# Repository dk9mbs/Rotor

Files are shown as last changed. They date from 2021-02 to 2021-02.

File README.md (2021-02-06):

https://forum.pycom.io/topic/4625/simple-http-server

micropython	
========================

```
cd /tmp/venv
python3.7 -m venv micropython
. /tmp/venv/micropython/bin/activate

pip install esptool
pip install adafruit-ampy

esptool.py --port /dev/ttyUSB0 erase_flash
esptool.py --port /dev/ttyUSB0 --baud 115200 write_flash --flash_size=detect 0 /tmp/esp8266-20200911-v1.13.bin

pip freeze
```

## Access to the python console

### Start picocom

```

ampy -p /dev/ttyUSB0 run --no-output rotor.py 
picocom --baud 115200 /dev/ttyUSB0

wget -O - --header "Rotor-Deg: 145" http://192.168.2.113/api/v1.0/rotor/0

```

### Exit picocom

```
ctrl-a ctrl-x
```

## Quellen

[1. Getting started with MicroPython on the ESP8266 — MicroPython 1.13 documentation](https://docs.micropython.org/en/latest/esp8266/tutorial/intro.html)

[Unable to exit serial tool · Issue #67 · amperka/ino · GitHub](https://github.com/amperka/ino/issues/67)

<https://www.digikey.com/en/maker/projects/micropython-basics-load-files-run-code/fb1fcedaf11e4547943abfdd8ad825ce>

https://github.com/micropython/micropython-lib/blob/master/traceback/traceback.py

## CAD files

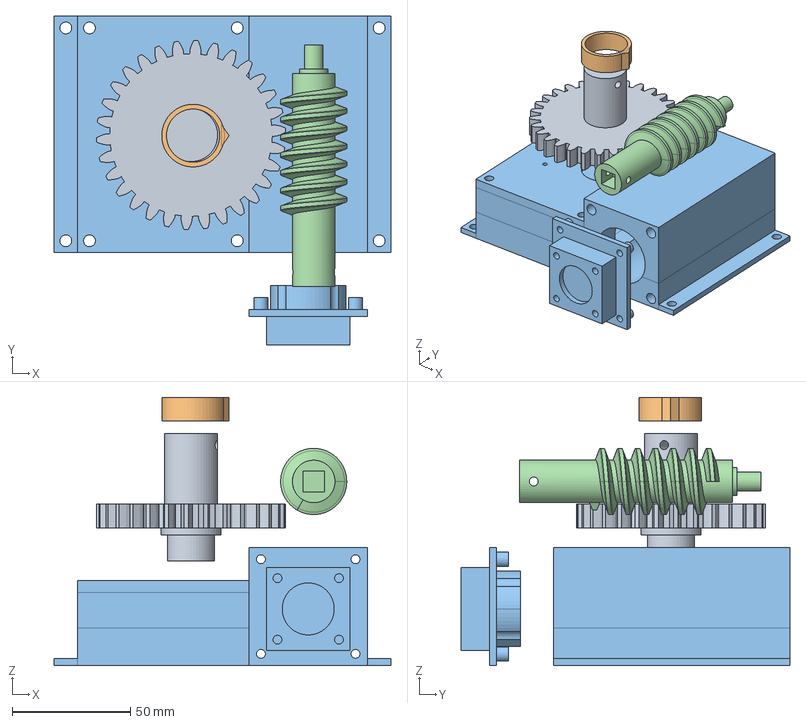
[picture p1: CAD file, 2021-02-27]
3D/assembly.FCStd
142.5 x 139.0 x 113.5 mm
Rotor_Antrieb_001
Rotor_Endabschalter_001
Rotor_Gehäuse_001
Rotor_Schnecke_001

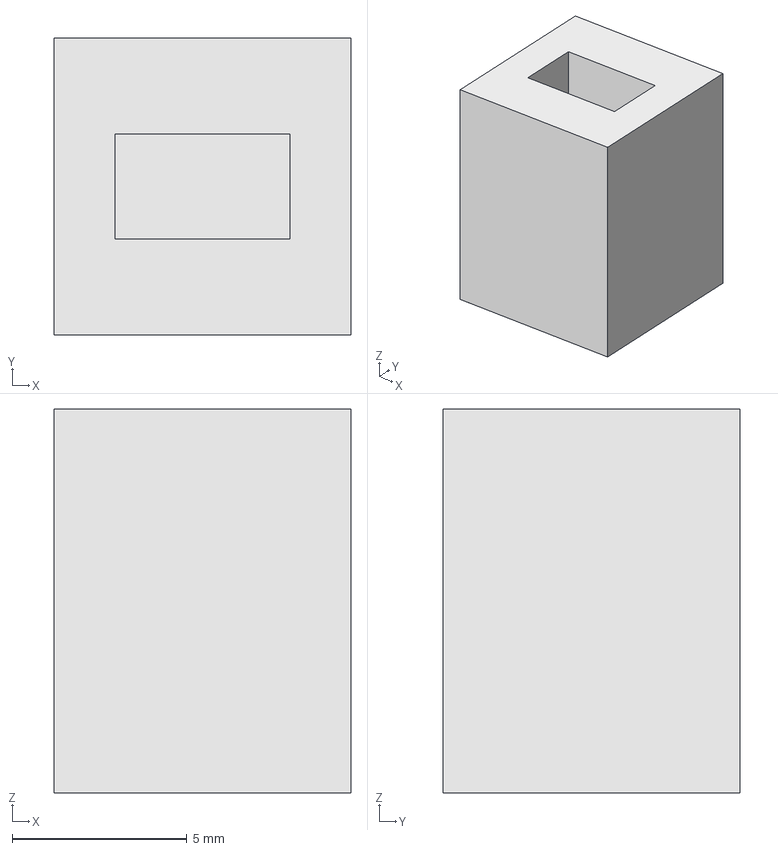
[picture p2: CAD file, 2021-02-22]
3D/Rotor_Schnecke_28BYJ-48_Adapter.FCStd
8.50 x 8.50 x 11.0 mm

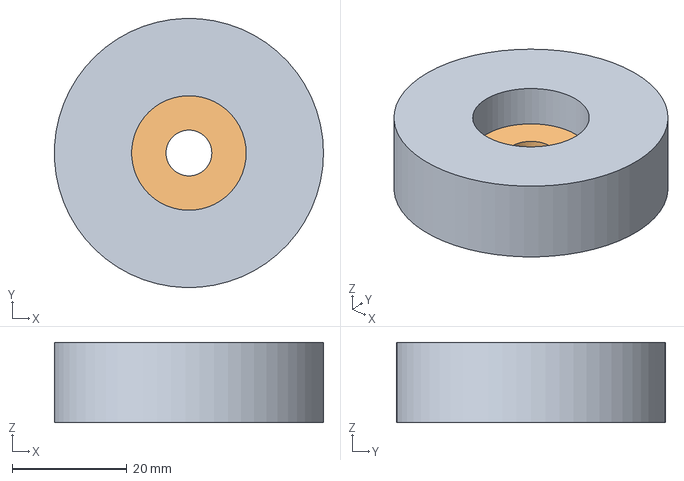
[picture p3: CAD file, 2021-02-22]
3D/Normteile.FCStd
47.0 x 47.0 x 14.0 mm
Kugellager 47mm Aussen 20mm Innen
Kugellager 22mm Aussen 8mm innen

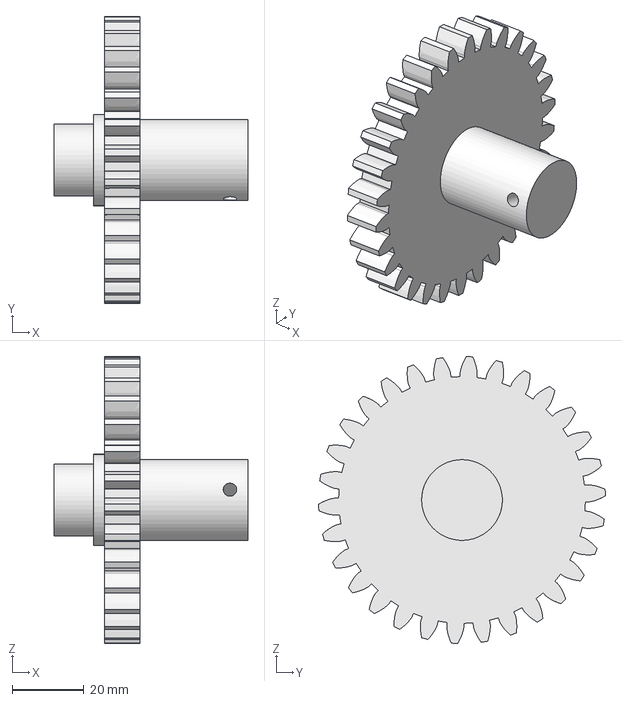
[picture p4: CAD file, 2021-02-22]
3D/Rotor_Antrieb.FCStd
54.0 x 80.0 x 80.0 mm

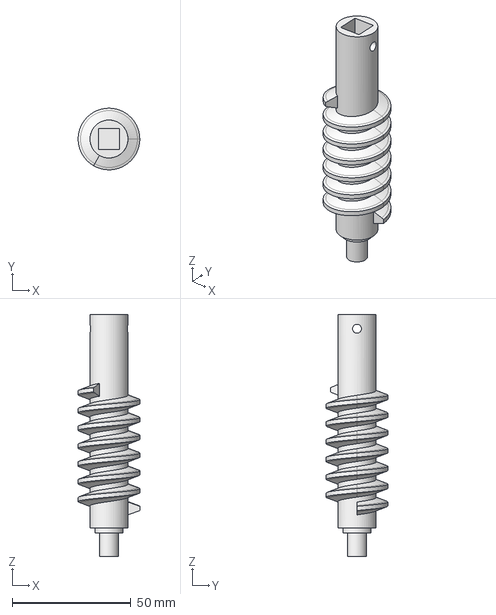
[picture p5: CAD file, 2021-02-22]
3D/Rotor_Schnecke.FCStd
26.0 x 26.0 x 102.0 mm

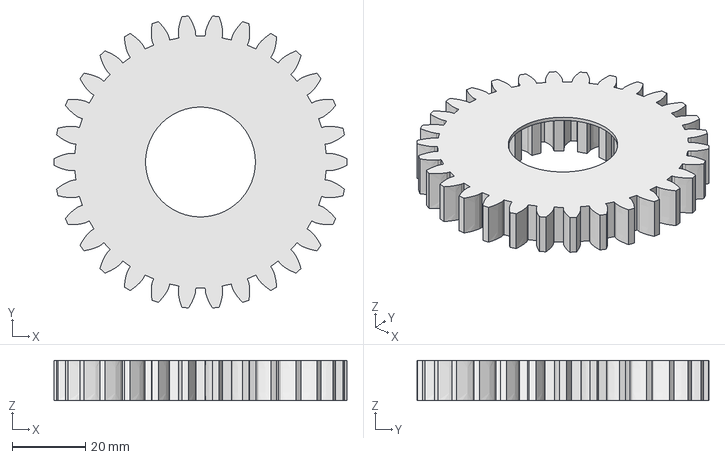
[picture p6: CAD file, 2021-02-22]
3D/Rotor_Adapter_Zahnrad.FCStd
80.0 x 79.7 x 11.0 mm

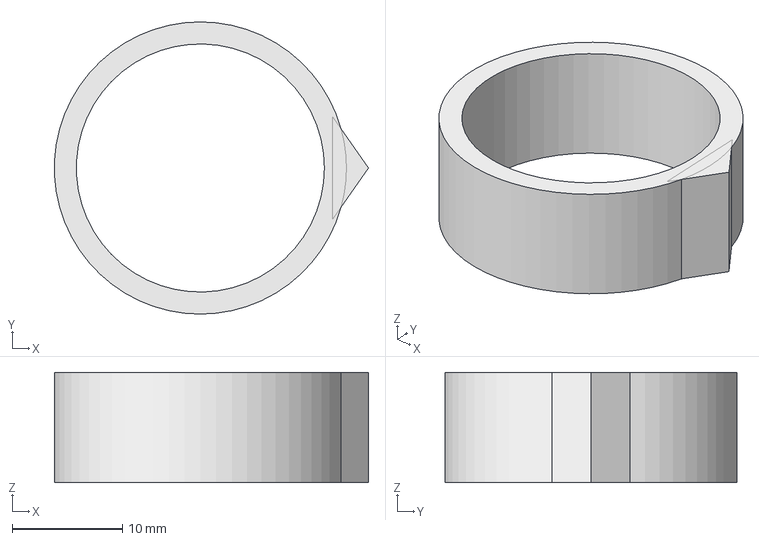
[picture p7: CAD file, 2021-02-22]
3D/Rotor_Endabschalter.FCStd
28.5 x 26.5 x 10.0 mm

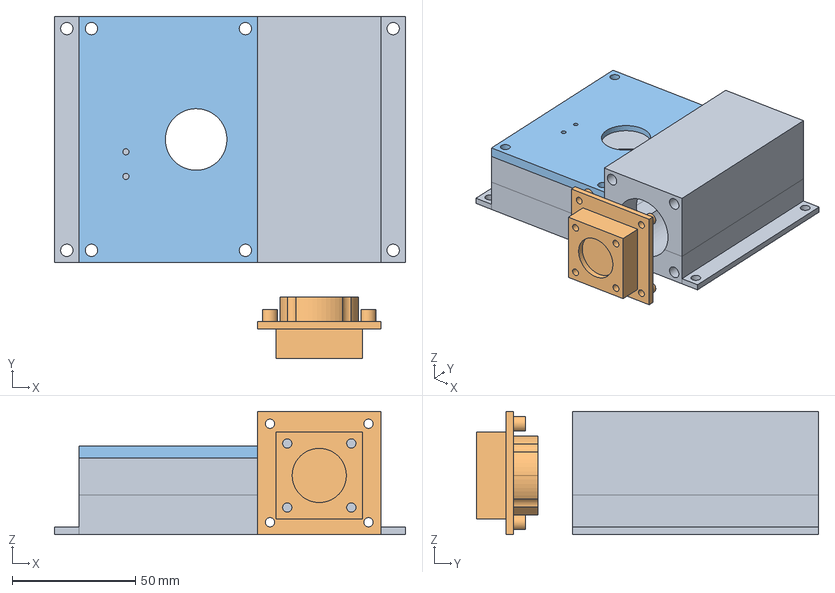
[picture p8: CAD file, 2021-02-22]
3D/Rotor_Gehäuse.FCStd
142.5 x 139.0 x 50.0 mm
Verschluss Tunnel Vorn
Deckel Stirnrad

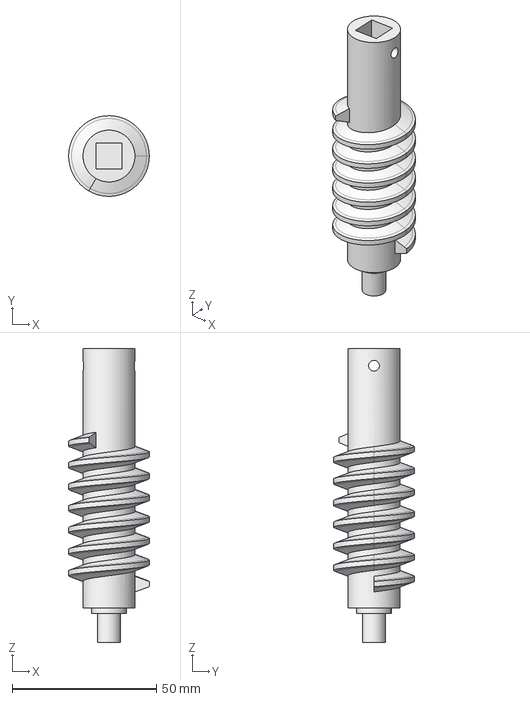
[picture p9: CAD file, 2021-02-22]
3D/Rotor_Schnecke_9mm.FCStd
28.0 x 28.0 x 102.0 mm

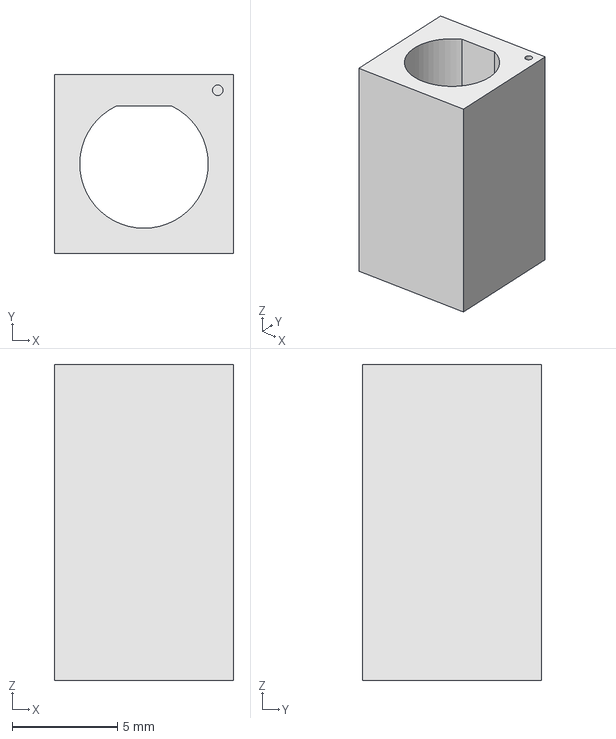
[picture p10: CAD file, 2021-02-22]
3D/Rotor_Schnecke_Nema14_Adapter.FCStd
8.50 x 8.50 x 15.0 mm

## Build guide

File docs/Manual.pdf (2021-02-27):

DK9MBS 3D Rotor V1.0

## Inhaltsverzeichnis

## Einrichtung

Die Setup Oberfläche der Rotors ist über einen beliebigen Webbrowser erreichbar. Bei gültiger WLAN Konfiguration meldet sich der Rotor automatisch am WLAN an und gibt die vom Router zugewiesene IP Adresse via Display und Serieller Schnittstelle aus (siehe dazu Kapitel Ausgabe). Beim ersten Start des Rotors oder bei ungültiger WLAN Konfiguration (WLAN am Standort nicht verfügbar, Passwort wurde geändert etc.) spannt der Rotor automatisch das WLAN „rotor.dk9mbs.de“ auf und zeigt das Passwort am LCD Display für ca. 2 Sekunden an. Im AP Modus ist der Rotor unter der IP Adresse 192.168.4.1 erreichbar.

## Setup

In der Setup Oberfläche können alle für den Betrieb des Rotors notwendigen Parameter hinterlegt.

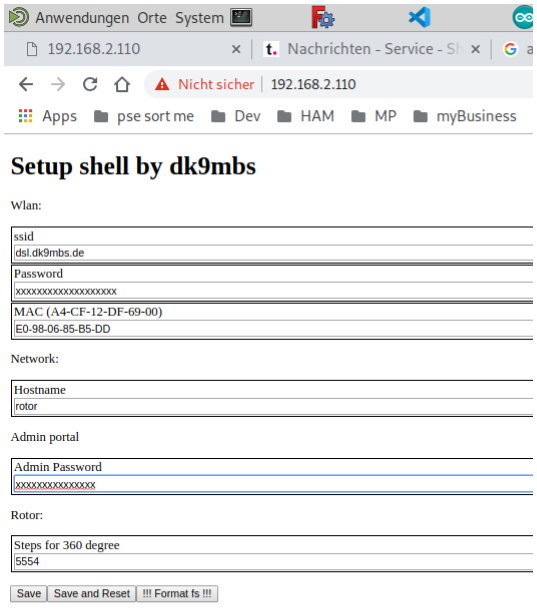
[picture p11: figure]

WLAN
ssid | Die WLAN ssid ID
Password | WLAN Passwort
MAC | Hier kann die MAC Adresse der ESP WLAN Netzwerkschnittstelle ändern.

Network
Hostname | Der Hostname unter dem sich der Rotor am DHCP Server registriert.

Admin Portal
Admin Password | Passwort für das Setup. Dieses Passwort wird auch für den AP Modus verwendet.

Rotor
Steps for 360 degree | Anzahl Schritte die der Motor für eine komplette Umdrehung benötigt (von Endschalter max. zu Endschalter min.). Durch löschen dieses Eintrags werden beim nächsten Neustart des Rotors dieSchritte automatisch neu ermittelt.

## Protokoll

Zur Rotor Steuerung mittels PC kommt ein generisches HTTP Protokoll zum Einsatz. Beispielsweise kann der Rotor mit „wget“ auf einfache Weise gesteuert werden:

wget -O – "http://[IP Adresse des Rotors]/api?command=[Kommando]&[Weitere Parameter]“

## Api

Neue Position setzen
Fährt den Rotor an eine neue Position. Als Argument „deg“ sind numerische Werte zwischen 0 und 360 (Grad) zulässig.

wget -O – "http://[IP Adresse des Rotors]/api?command=MOVE&deg=45“

Der HTTP Request arbeitet nicht blockierend – d.h. Nach Annahme des neuen Wertes liefert der Rotor sofort den HTTP Code 200 zurück. Erst danach startet der Motor. Eine Positionsänderung ist auch während laufenden Motor möglich.

Aktuelle Position abfragen
Liefert die aktuelle Position des Rotors.

wget -O – "http://[IP Adresse des Rotors]/api?command=GETCURRENTPOS“

Text auf dem Display ausgeben
Gibt einen Text auf dem Display in der obersten Zeile aus (max. 16 Zeichen).

wget -O – "http://[IP Adresse des Rotors]/api?command=SETDISPLAY&line0=Hallo“

In diesem Beispiel wird „Hallo“ in der ersten Zeile des LCD Displays angezeigt.

## Firmware (DK9MBS-Rotor-OS)

Die Architektur der Firmware basiert auf der „finate stamachine theory“. In dieser Theorie befindet sich die Firmware immer in einem definierten Zustand. Über Bedingungen kann ein Wechsel des Zustandes erzwungen werden.

Diagramm

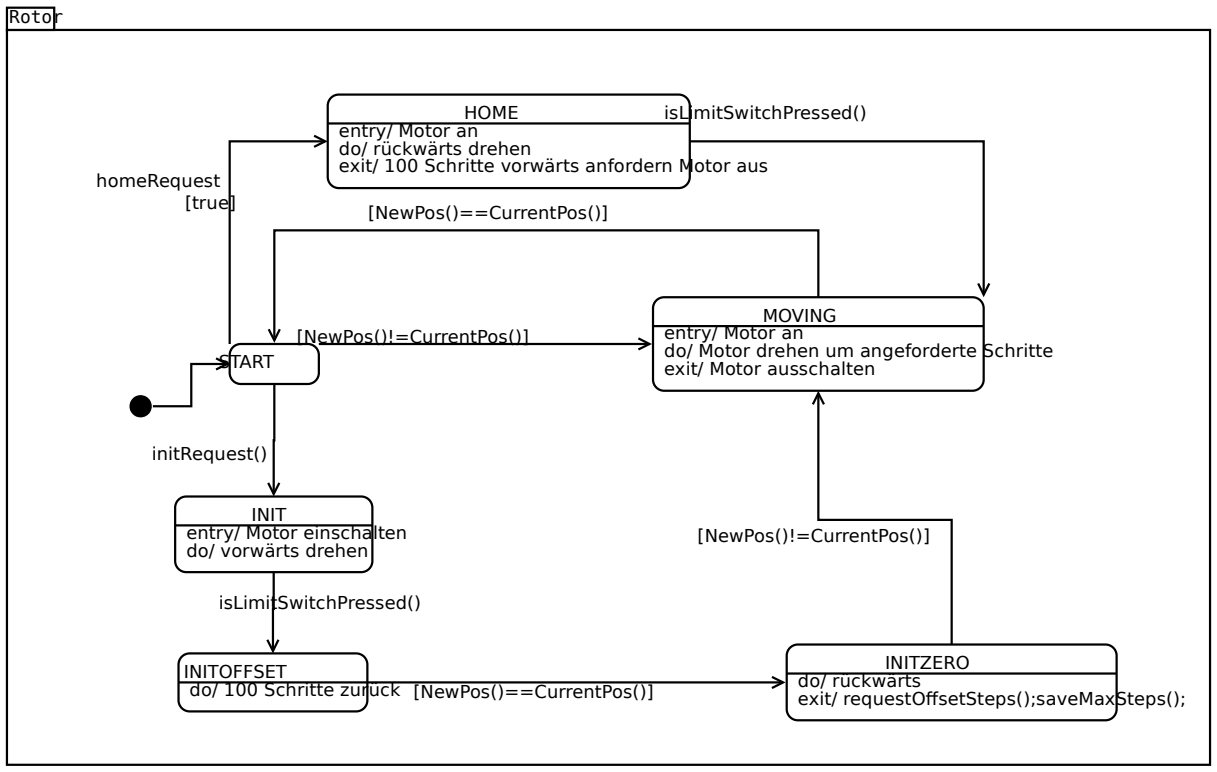
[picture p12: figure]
Rotor; START; [NewPos()!=CurrentPos()]; INIT entry/ Motor einschalten do/ vorwärts drehen; initRequest(); MOVING entry/ Motor an; exit/ Motor ausschalten; HOME entry/ Motor an do/ rückwärts drehen; INITOFFSET do/ 100 Schritte zurück; INITZERO do/ rückwärts exit/ requestOffsetSteps();saveMaxSteps();; [NewPos()==CurrentPos()]; isLimitSwitchPressed(); [true]; homeRequest

do/ Motor drehen um angeforderte Schritte exit/ 100 Schritte vorwärts anfordern Motor aus

Quellcode
Der Quellcode kann unter Github öffentlich eingesehen werden. Die Adresse lautet:

https://github.com/dk9mbs/Rotor/blob/dev/fw-8266-arduino/fw-8266-arduino.ino

Bibliotheken

LiquidCrystal_I2C https://github.com/lucasmaziero/ LiquidCrystal_I2C

Manuell installieren

Einstellungen Arduino IDE
Zunächst muss das ESP Board der Arduino IDE bekanntgemacht werden. Dazu muss die URL der Board Definition unter Datei → Voreinstellungen als Zusätzliche Boardverwalter-URL hinterlegt werden [4].

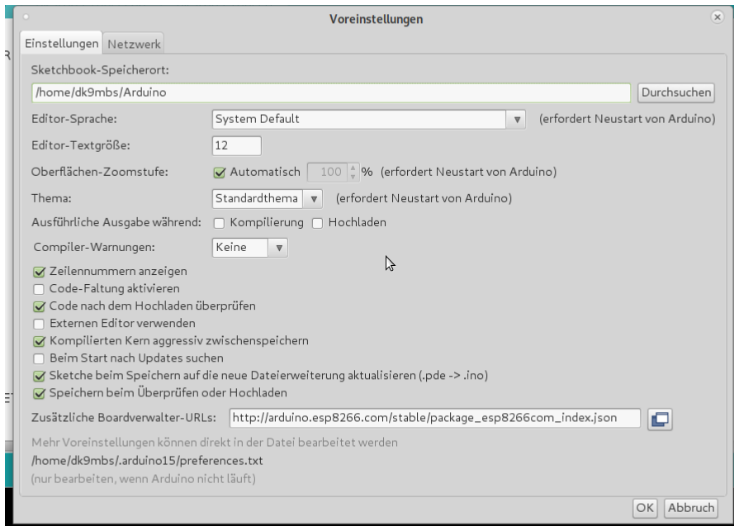
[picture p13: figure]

Die zu hinterlegende URL lautet: http://arduino.esp8266.com/stable/package_esp8266com_index.json

Jetzt kann unter Werkzeuge das richtige Board ausgewählt werden: NodeMCU 0.9 (ESP-12 Module).

## Mainboard

Auf dem Rotor Mainboard befinden sich sowohl NodeMCU mit ESP8266, DRV8825 als auch sämtliche Anschlüsse und die Stromversorgung (12V und 5V).

## Anschlüsse

Die Anschlüsse sind mit C1 – C5 gekennzeichnet.

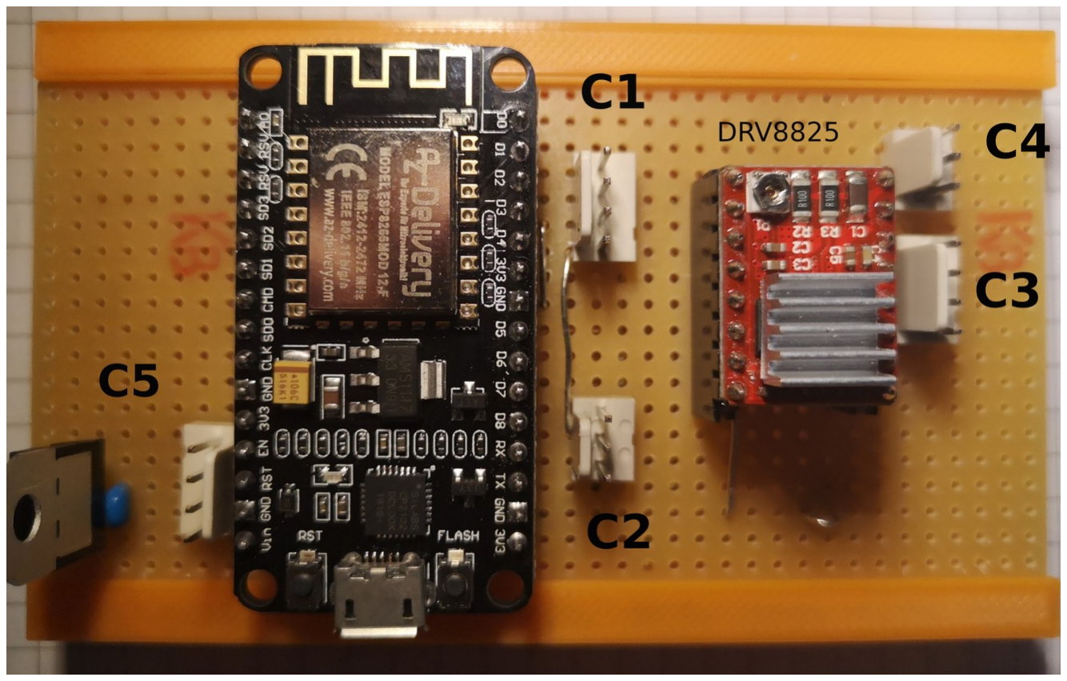
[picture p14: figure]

Connector | Pin (von oben nach unten) | Beschreibung
C1 | | I2C Bus
| 1 | SCL
| 2 | SDA
| 3 | GND
| 4 | +5V (Vin)
C2 | | Endschalter
| 1 | nc
| 2 | Taster
| 3 | GND
C3 | | Stepper
| 1 | B2
| 2 | B1
| 3 | A1
| 4 | A2
C4 | | Power (12V)

| 1 | nc
| 2 | +12V in
| 3 | GND
C5 | | Nicht benutzt
| 1
| 2
| 3
| 4 | + 5V (Vin)

## Elektronische Komponenten

## NodeMCU mit ESP8266

Verfügbare GPIO Pin‘s
Nicht alle Pins können frei verwendet werden. Beispielsweise darf Pin 2 beim Booten nicht auf Masse gezogen sein.
GPIO | Function | State | Einschränkungen
0 | Boot mode select | 3.3V | No Hi-Z
1 | TX0 | - | Not usable during Serial transmission
2 | Boot mode select TX1 | 3.3V (boot only) | Don’t connect to ground at boot time Sends debug data at boot time
3 | RX0 | - | Not usable during Serial transmission
4 | SDA (I²C) | - | -
5 | SCL (I²C) | - | -
6-11 | Flash connection | x | Not usable, and not broken out
12 | MISO (SPI) | - | -
13 | MOSI (SPI) | - | -
14 | SCK (SPI) | - | -
15 | SS (SPI) | 0V | Pull-up resistor not usable
16 | Wake up from sleep | - | No pull-up resistor, but pull-down instead Should be connected to RST to wake up

Quelle: [1]

Verwendung der GPIO Pins

Pin | Verwendung | Bemerkung
12 | 8825 - Step
13 | 8825 - Direction
14 | 8825 - Enable
4 | LCD (SDA) | 10K Pulldown
5 | LCD (SCL)
2 | Endschalter | 4,7K Pullup Schließer

Pinbelegung
In diesem Manual wird immer von den GPIO Bezeichnungen gesprochen; nicht von den auf dem Board aufgedruckten Aliassen.

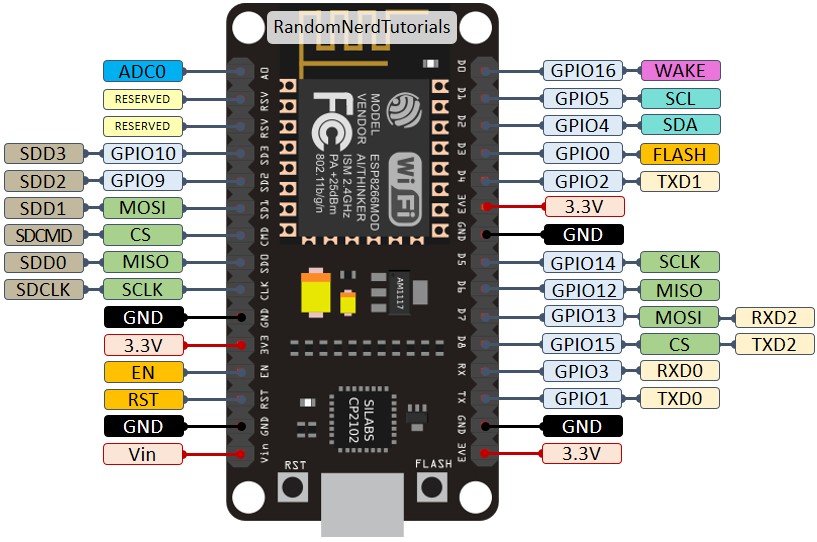
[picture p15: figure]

## Motortreiber DRV8825

Bei dem DRV8825 handelt es sich um einen intelligenten Schrittmotortreiber. Dieser Treiber benötigt vom Mikrocontroller lediglich Schritt Impulse. Die eigentliche Ansteuerung des Schrittmotors übernimmt der Treiber selbst.

Pinbelegung
Vor dem Betrieb mit einem neuen Motor muss der maximale Strom mit dem Potentiometer laut Herstellerangabe eingestellt werden.

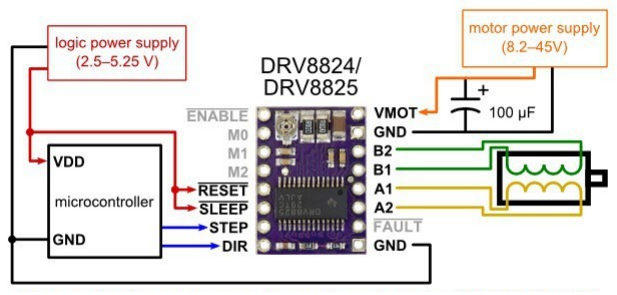
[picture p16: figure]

Konfiguration der Schrittgröße
Über die Anschlüsse „M0“ bis „M2“ kann die Schrittgröße konfiguriert werden. Nach Änderung der Schrittgröße muss im Setup Modus des Rotors diese auf 0 gesetzt werden. Nach dem nächsten Neustart ermittelt der Rotor dann selbstständig die Anzahl der Schritte die für eine 360 Grad Drehung benötigt werden und speichert diese dauerhaft.
M0 | M1 | M2 | Schritt Auflösung | Anzahl Schritte für eine Umdrehung
0 | 0 | 0 | 1 | 200
1 | 0 | 0 | 1/2 | 400
0 | 1 | 0 | 1/4 | 800
1 | 1 | 0 | 1/8 | 1600
0 | 0 | 1 | 1/16 | 3200
1 | 0 | 1 | 1/32 | 6400

Signal am Step Eingang
Am Step Eingang des DRV8825 ist beim Bewegen des Rotors ein 50Hz (20ms Periodendauer) Signal zu erkennen.

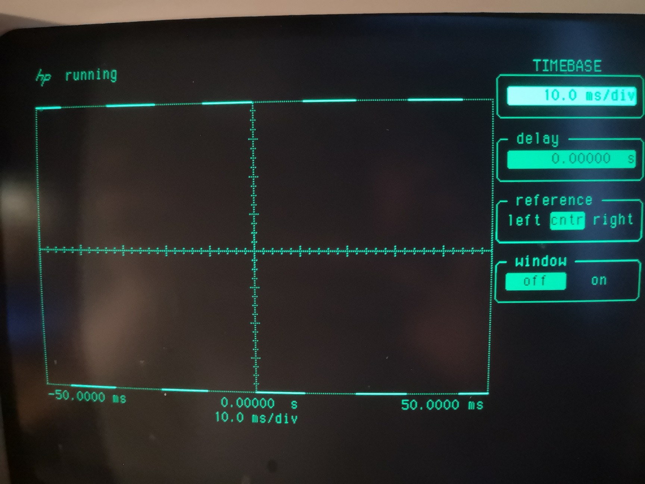
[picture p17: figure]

## Ausgabe

Die Ausgabe von Meldungen erfolgt bei dem Rotor auf 2 Wegen:
- Über den Seriellen Port mit 115200 Baud
- Über ein am I2C Bus angeschlossenes LCD Display
Das LCD Display zeigt im Betrieb die IP Adresse des Rotors im Netzwerk und die aktuelle Position in (Alt) Grad an.

LCD Display mit I2C Adapter

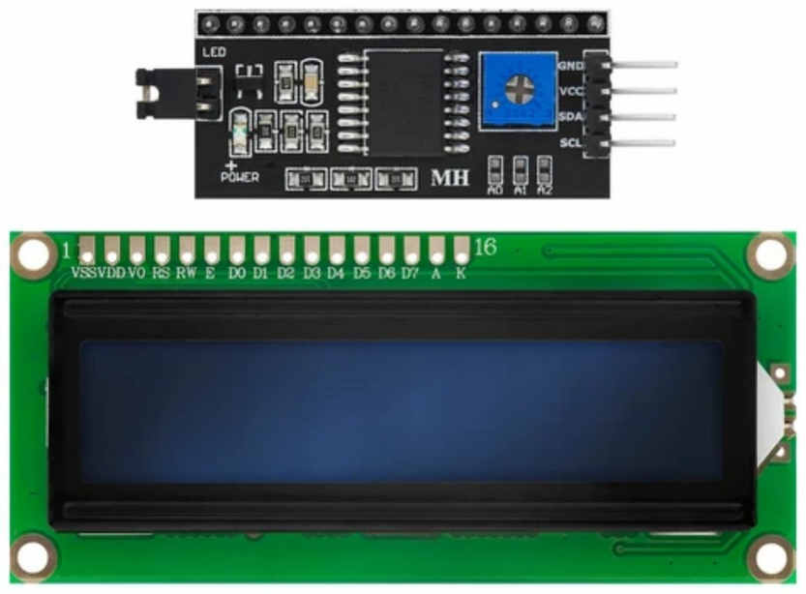
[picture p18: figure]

## 3D Druck

Die Mechanik des Rotors besteht lediglich aus 3D druckbaren Komponenten und einigen wenigen Standardbauteilen die in jedem Baumarkt verfügbar sind.

## Explosionszeichnung

Der Rotor besteht aus einzelnen Bauteilen. Als Druckmaterial wird PLA empfohlen.

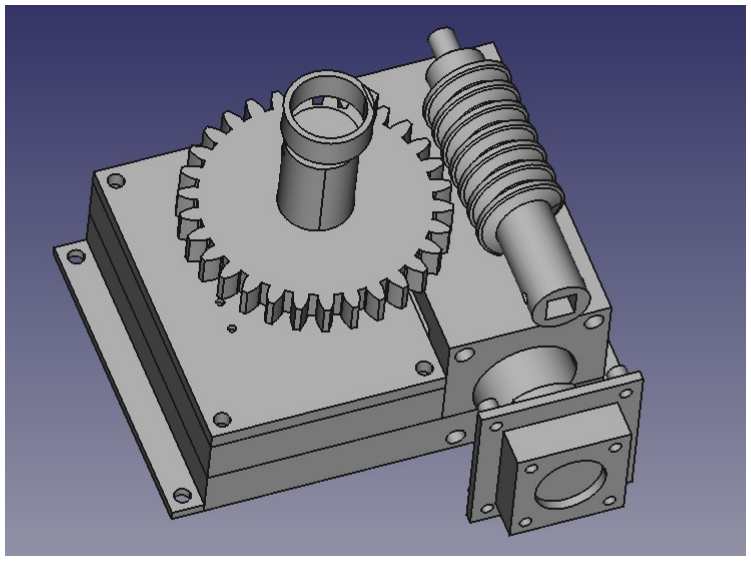
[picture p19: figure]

## Dateien

Die Dateien stehen im Freecad Format zur Verfügung. Die Druckdauer beträgt je nach Einstellung und Geschwindigkeit des Druckers ca. 60 Stunden. Die Freecad Dateien können hier runter geladen werden:
https://github.com/dk9mbs/Rotor/tree/master/3D
Eine kurze Beschreibung der einzelnen Teile befindet sich in diesem Handbuch im Kapitel „Stückliste“

## Stückliste

## Elektronik / Mechanik

Menge | Teil
1 | DRV8825
1 | NodeMCU mit 8266
1 | LCD Display 16X2 Zeichen
1 | LCD I2C Adapter
1 | Kugellager 47mm Außendurchmesser
1 | Kugellager 22mm Außendurchmesser
1 | Endschalter (Taster Schließer)
1 | M3 Gewindestange
4 | M4 Schrauben
4 | M4 Muttern
8 | M3 Muttern
8 | M3 Unterlegscheiben

## 3D Teile

Dateiname | Baugruppe
Rotor_Antrieb.FCStd | Zahnrad mit Antriebsachse
Rotor_Endabschalter.FCStd | Endschalter Ring
Rotor_Gehäuse.FCStd | Gehäuse mit Deckel und Nema Befestigung
Rotor_Schnecke_9mm.FCStd | Antriebsschnecke
Rotor_Schnecke_Nema14_Adapter.FCStd | Adapter Motor - Schnecke

## Verbesserungen in den nächsten Versionen

In einer nächsten Versionen sind Verbesserungen sowohl an der Firmware, der Elektronik und der Mechanik geplant.

## Verbesserungen

Problem | Lösung | Prio (1-9)
Update | Over the Air Updates | 9
Fehlende manuelle Bedienung (keine freien GPIO Pin‘s) | Anschluss I2C Port Expander | 1
Laute Motorgeräusche | Dämpfung zwischen Motor und Gehäuse | 2
Drehmoment nicht bekannt | Messen mit Kofferwaage | 1
2. Rotor

## Quellen

[1] https://lastminuteengineers.com/drv8825-stepper-motor-driver-arduino-tutorial/
[2] https://tttapa.github.io/ESP8266/Chap04%20-%20Microcontroller.html
[3] https://de.wikipedia.org/wiki/Endlicher_Automat
[4] https://m.heise.de/make/artikel/ESP-Boards-mit-der-Arduino-IDE-programmieren-4130861.html?seite=all (https://m.heise.de/make/artikel/ESP-Boards-mit-der-Arduino-IDE-programmieren-4130861.html?seite=all)
[5] https://github.com/dk9mbs/Rotor/tree/master/3D

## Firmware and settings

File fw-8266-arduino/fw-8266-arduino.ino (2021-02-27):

#ifdef ESP32
#pragma message(THIS EXAMPLE IS FOR ESP8266 ONLY!)
#error Select ESP8266 board.
#endif

#include "dk9mbs_tools.h"
#include <ESP8266WiFi.h>
#include <FS.h>
#include <ESP8266WebServer.h>
#include <ESP8266HTTPClient.h>
#include <LiquidCrystal_I2C.h>
#include "config.h"

#define ROT_AZI_STEP 12
#define ROT_AZI_DIR 13
#define ROT_AZI_ENABLED 14
#define ROT_AZI_LIMIT_SWITCH 2
#define SW1PIN 4
#define SW2PIN 5
#define LIMIT_SWITCH_OFFSET 100

enum {START, MOVING, INIT,INITOFFSET,INITZERO, HOME,HOMEOFFSET};
enum {FORWARD, BACKWARD, STOPPED};

class Rotor {
  private:
    int _state;
    int _newPos;
    int _currentPos;
    int _maxSteps;
    boolean _initRequest;
    boolean _homeRequest;
       
  public:
    Rotor();

    boolean getInitRequest();
    void setInitRequest(boolean value);
    boolean getHomeRequest();
    void setHomeRequest(boolean value);
    
    int getState();
    void setState(int value);
  
    int getNewPos();
    void setNewPos(int value);

    int getCurrentPos();
    void setCurrentPos(int value);
    void incrementCurrentPos();
    void decrementCurrentPos();

    void incrementMaxSteps();
    int getMaxSteps();
    void setMaxSteps(int value);

    int getCurrentPosDeg();
    void setNewPosDeg(int deg);

};
Rotor::Rotor() {
  Rotor::_state=START;
  Rotor::_newPos=0;
  Rotor::_currentPos=0;
  Rotor::_maxSteps=0;
  Rotor::_initRequest=false;
}
int Rotor::getNewPos() {
  return Rotor::_newPos;
}
void Rotor::setNewPos(int value) {
  Rotor::_newPos=value;
}
int Rotor::getCurrentPos(){
  return Rotor::_currentPos;
}
void Rotor::setCurrentPos(int value){
  Rotor::_currentPos=value;
}
void Rotor::incrementCurrentPos(){
  Rotor::_currentPos++;
}
void Rotor::decrementCurrentPos(){
  Rotor::_currentPos--;
}
void Rotor::incrementMaxSteps(){
  Rotor::_maxSteps++;
}
int Rotor::getMaxSteps() {
  return Rotor::_maxSteps;
}
void Rotor::setMaxSteps(int value){
  Rotor::_maxSteps=value;
}
void Rotor::setInitRequest(boolean init) {
  Rotor::_initRequest=init;
}
boolean Rotor::getInitRequest() {
  return Rotor::_initRequest;
}

void Rotor::setHomeRequest(boolean init) {
  Rotor::_homeRequest=init;
}
boolean Rotor::getHomeRequest() {
  return Rotor::_homeRequest;
}


int Rotor::getState() {
  return Rotor::_state;
}
void Rotor::setState(int value){
  Rotor::_state=value;
}

int Rotor::getCurrentPosDeg() {
  float deg;
  deg=((float)360/(float)Rotor::_maxSteps)*(float)Rotor::_currentPos;
  return (int)deg;
}

void Rotor::setNewPosDeg(int deg) {
  int steps;
  steps=((float)Rotor::_maxSteps/(float)360)*(float)deg;
  Rotor::_newPos=(int)steps;
}

WiFiClient espClient;
ESP8266WebServer httpServer(80);
HTTPClient http;
LiquidCrystal_I2C lcd(0x27, 16, 2);
Rotor rotor;
boolean runSetup=false;


void setup()
{
  Serial.begin(115200);
  lcd.begin();

  disableStepper(rotor);
  printLcd(lcd, 0,1, "init",1);
  
  setupIo();
  printLcd(lcd, 5,1, ".",0);
  setupFileSystem();
  printLcd(lcd, 6,1, ".",0);

  Serial.print("Setup:");
  Serial.println(digitalRead(SW1PIN));
  Serial.print("adminpwd: ");
  Serial.println(readConfigValue("adminpwd"));
  Serial.print("Steps for 360 degree: ");
  Serial.println(readConfigValue("rotorsteps"));
  printLcd(lcd, 7,1, ".",0);
  delay (1000);  

  if(runSetup) {
    setupWifiAP();
    setupHttpAdmin();
  } else {
    setupHttpAdmin();
    if (!setupWifiSTA(readConfigValue("ssid").c_str(), readConfigValue("password").c_str(), readConfigValue("mac").c_str())) {
      // Fallback start the AP mode!
      printLcd(lcd, 0,0, "No WLAN! AP mode",0);
      setupWifiAP();
      delay(2500);
    }

    Serial.println("Waiting for commands over http...");
    delay(1000);

    rotor.setMaxSteps(readMaxStepsFromSetup());
    if(rotor.getMaxSteps()==0){
      Serial.println("No data for stepper found!");
      rotor.setInitRequest(true);
    } else {
      Serial.println("Move stepper to home position");
      rotor.setHomeRequest(true);
    }
  } 
}

void loop()
{
  static unsigned long lastSw1=0;
  static unsigned long lastSw2=0;

  httpServer.handleClient(); 
  rotorStepperStateMaschine(rotor);

  if(digitalRead(SW1PIN)==HIGH && millis() > lastSw1+500) {
    //Serial.println("SW1");
    lastSw1=millis();
  }

  if(digitalRead(SW2PIN)==HIGH && millis() > lastSw2+500) {
    //Serial.println("SW2");
    lastSw2=millis();
  }

}

void rotorStepperStateMaschine(Rotor &rotor) {
  int state;
  static int lastEntryState=-1;
  static unsigned long lastLoop=0;
  static unsigned long lastLcd=0;
  
  state=rotor.getState();
  
  int newPos=rotor.getNewPos();
  int currentPos=rotor.getCurrentPos();
  int rotorDir;

  rotorDir=calculaterotorDirection(rotor);

  switch (state) {
    case HOME:
      if (state!=lastEntryState){
        rotor.setHomeRequest(false);
        enableStepper(rotor);
        lastEntryState=state;
        Serial.println("Entry point HOME");
        clearLcdLine(lcd,1);
        printLcd(lcd, 0,1, "go home",0);
      }else if(isLimitSwitchPressed(rotor)==true) {
        rotor.setCurrentPos(-LIMIT_SWITCH_OFFSET);
        rotor.setNewPos(0);
        disableStepper(rotor);
        state=MOVING;
      } else {
        if (millis() > lastLoop + 1) {
          doStep(BACKWARD, rotor);
          lastLoop=millis();    
        }
      }      
      break;
    case START:
      if (state!=lastEntryState){
          lastEntryState=state;

          if(rotor.getHomeRequest()) state=HOME;
          if(rotor.getInitRequest()) state=INIT;
          Serial.println("Entry point START");
          clearLcdLine(lcd,1);
          printLcd(lcd, 0,1, "Pos:"+String(rotor.getCurrentPosDeg())+"\337",0); //col, row

      } else if(newPos!=currentPos){
          Serial.println(newPos);
          Serial.println("Statemaschine is starting...");
          enableStepper(rotor);
          state=MOVING;
      } else {
        // no do actions in this state!!!
      }
      break;
    case INIT:
      if (state!=lastEntryState){
        rotor.setInitRequest(false);
        enableStepper(rotor);
        lastEntryState=state;
        Serial.println("Entry point INIT");
        clearLcdLine(lcd,1);
        printLcd(lcd, 0,1, "move to max",0);
      }

      if(isLimitSwitchPressed(rotor)==true) {
        rotor.setNewPos(rotor.getCurrentPos()-LIMIT_SWITCH_OFFSET);
        state=INITOFFSET;
      } else {
        if (millis() > lastLoop + 1) {
          doStep(FORWARD, rotor);
          lastLoop=millis();    
        }
      }
      break;

    case INITOFFSET:
      if (state!=lastEntryState){
          lastEntryState=state;
          Serial.println("Entry point INITOFFSET");
          clearLcdLine(lcd,1);
          printLcd(lcd, 0,1, "move to offset",0);
      }

      if(newPos==currentPos){
        disableStepper(rotor);
        state=INITZERO;
      } else {
        if (millis() > lastLoop + 1) {
          doStep(BACKWARD, rotor);
          lastLoop=millis();
        }
      }
      break;    
    case INITZERO:
      if (state!=lastEntryState){
          enableStepper(rotor);
          rotor.setMaxSteps(0);
          lastEntryState=state;
          Serial.println("Entry point INITZERO");
          clearLcdLine(lcd,1);
          printLcd(lcd, 0,1, "move home",0);
      }
      
      if(isLimitSwitchPressed(rotor)==true) {
        rotor.setCurrentPos(LIMIT_SWITCH_OFFSET*-1);
        rotor.setNewPos(0);
        Serial.println("Steps required for 360 degree:"+(String)rotor.getMaxSteps());
        saveConfigValue("rotorsteps", (String)(rotor.getMaxSteps()-LIMIT_SWITCH_OFFSET));
        state=MOVING;
      } else {
        if (millis() > lastLoop + 1) {
          if(doStep(BACKWARD, rotor)==true){
            rotor.incrementMaxSteps();
          }
          lastLoop=millis();    
        }
      }
      break;

    case MOVING:
      if (state!=lastEntryState){
        enableStepper(rotor);          
        lastEntryState=state;
        Serial.println("Entry point MOVING");
        clearLcdLine(lcd,1);
        printLcd(lcd, 0,1, "moving...",0); 
      }
    
      if(newPos==currentPos){
        disableStepper(rotor);
        state=START;
      } else {
        if (millis() > lastLoop + 10) {
          doStep(rotorDir, rotor);
          lastLoop=millis();
        }

      }
      
      break;
  }

  rotor.setState(state);
}

/*
 * 
 * Helper functions
 * 
 */

void enableStepper(Rotor &rotor) {
  digitalWrite(ROT_AZI_ENABLED, LOW);
}

void disableStepper(Rotor &rotor) {
  digitalWrite(ROT_AZI_ENABLED, HIGH);
}

boolean isLimitSwitchPressed(Rotor &rotor) {
  if(digitalRead(ROT_AZI_LIMIT_SWITCH)==LOW) {
    return true;
  } else {
    return false;
  }
}

boolean doStep(int rotorDir, Rotor &rotor) {
  boolean dirPin=LOW;
  boolean result=false;
  
  if (rotorDir==BACKWARD) {
    dirPin=HIGH;
    //dirPin=LOW;
  }
  
  digitalWrite(ROT_AZI_DIR, dirPin);

  if (digitalRead(ROT_AZI_STEP)){
      digitalWrite(ROT_AZI_STEP,LOW);
      //increment or decrement the current pos only at every low high pass
      result=true;
      if (rotorDir==BACKWARD) {
        rotor.decrementCurrentPos();
      } else {
        rotor.incrementCurrentPos();
      }
    } else {
    digitalWrite(ROT_AZI_STEP, HIGH);
  }

  return result;
}

int calculaterotorDirection(Rotor &rotor) {
  int rotorDir;
  rotorDir=STOPPED;
  
  if (rotor.getNewPos()<rotor.getCurrentPos()) {
    rotorDir=BACKWARD;
  } else {
    rotorDir=FORWARD;
  }

  return rotorDir;
}

int readMaxStepsFromSetup(){
  String tmp;
  tmp=readConfigValue("rotorsteps");
  if(tmp=="" || tmp=="0"){
    return 0;
  }

  return tmp.toInt();
}

/*
   getCommandValue
   Return a part of a complete Stepper command.
   Example:
   getCommandValue("MF 100", ' ',2)
   Return 100
*/
String getCommandValue(String data, char separator, int index)
{
  int found = 0;
  int strIndex[] = {0, -1};
  int maxIndex = data.length() - 1;

  for (int i = 0; i <= maxIndex && found <= index; i++) {
    if (data.charAt(i) == separator || i == maxIndex) {
      found++;
      strIndex[0] = strIndex[1] + 1;
      strIndex[1] = (i == maxIndex) ? i + 1 : i;
    }
  }

  return found > index ? data.substring(strIndex[0], strIndex[1]) : "";
}


String createIoTDeviceAddress(String postfix) {
  String address=String(readConfigValue("mac")+"."+postfix);
  address.replace("-","");
  return address;  
}

void setupHttpAdmin() {
  httpServer.on("/",handleHttpSetup);
  httpServer.on("/api",handleHttpApi);
  httpServer.onNotFound(handleHttp404);
  httpServer.begin();
}

void handleHttpApi() {
  String cmd=httpServer.arg("command");
  String steps=httpServer.arg("steps");
  String deg=httpServer.arg("deg");
  String line0=httpServer.arg("line0");
  String responseBody="api";
  
  if(cmd=="ping") {
    responseBody="pong";
  } else if(cmd=="MOVE") {

    if(rotor.getState()==INIT || rotor.getState()==INITOFFSET || rotor.getState()==INITZERO){
      httpServer.send(500, "text/html", "Rotor zeroinit in progress!"); 
      return;
      
    }
    //rotor.setNewPos(steps.toInt());
    rotor.setNewPosDeg(deg.toInt());
    Serial.println("New pos:"+((String)rotor.getNewPos()));
    Serial.println("Current pos:"+((String)rotor.getCurrentPos()));
  } else if (cmd=="GETCURRENTPOS") {
    responseBody=(String)rotor.getCurrentPos();
  } else if (cmd =="SETDISPLAY"){
    clearLcdLine(lcd,0);
    printLcd(lcd, 0,0, line0,0); //col, row
    responseBody=String(line0);
  }

  httpServer.send(200, "text/html", responseBody); 
}

void handleHttpSetup() {
    String pwd = readConfigValue("adminpwd");
    if (!httpServer.authenticate("admin", pwd.c_str())) {
      return httpServer.requestAuthentication();
    }
      
    if(httpServer.hasArg("CMD")) {
      Serial.println(httpServer.arg("CMD"));
      handleSubmit();
    }

    if(httpServer.hasArg("FORMATFS")) {
      Serial.println("Format FS");
      handleFormat();
    }
    if(httpServer.hasArg("RESET")) {
      Serial.println("Reset ...");
      handleReset();
    }

    String html =
    "<!DOCTYPE HTML>"
    "<html>"
    "<head>"
    "<meta name = \"viewport\" content = \"width = device-width, initial-scale = 1.0, maximum-scale = 1.0, user-scalable=0\">"
    "<title>DK9MBS-ROTOR-OS</title>"
    "<style>"
    "\"body { background-color: #808080; font-family: Arial, Helvetica, Sans-Serif; Color: #000000; }\""
    "</style>"
    "</head>"
    "<body>"
    "<h1>DK9MBS-Rotor-OS Setup</h1>"
    "<FORM action=\"/\" method=\"post\">"
    "<P>Wlan:"
    "<INPUT type=\"hidden\" name=\"CMD\" value=\"SAVE\"><BR>"
    "<div style=\"border-style: solid; border-width:thin; border-color: #000000;padding: 2px;margin: 1px;\"><div>ssid</div><INPUT style=\"width:99%;\" type=\"text\" name=\"SSID\" value=\""+ readConfigValue("ssid") +"\"></div>"
    "<div style=\"border-style: solid; border-width:thin; border-color: #000000;padding: 2px;margin: 1px;\"><div>Password</div><INPUT style=\"width:99%;\" type=\"text\" name=\"PASSWORD\" value=\""+ readConfigValue("password") +"\"></div>"
    "<div style=\"border-style: solid; border-width:thin; border-color: #000000;padding: 2px;margin: 1px;\"><div>MAC (A4-CF-12-DF-69-00)</div><INPUT style=\"width:99%;\" type=\"text\" name=\"MAC\" value=\""+ readConfigValue("mac") +"\"></div>"
    "</P>"
    "<P>Network:"
    "<div style=\"border-style: solid; border-width:thin; border-color: #000000;padding: 2px;margin: 1px;\"><div>Hostname</div><INPUT style=\"width:99%;\" type=\"text\" name=\"HOSTNAME\" value=\""+ readConfigValue("hostname") +"\"></div>"
    "</P>"
    "<P>Admin portal"
    "<div style=\"border-style: solid; border-width:thin; border-color: #000000;padding: 2px;margin: 1px;\"><div>Admin Password</div><INPUT style=\"width:99%;\" type=\"text\" name=\"ADMINPWD\" value=\""+ readConfigValue("adminpwd") +"\"></div>"
    "</P>"
    "<P>Rotor:"
    "<div style=\"border-style: solid; border-width:thin; border-color: #000000;padding: 2px;margin: 1px;\"><div>Steps for 360 degree</div><INPUT style=\"width:99%;\" type=\"text\" name=\"ROTORSTEPS\" value=\""+ readConfigValue("rotorsteps") +"\"></div>"
    "</P>"
    "<div>"
    "<INPUT type=\"submit\" value=\"Save\">"
    "<INPUT type=\"submit\" name=\"RESET\" value=\"Save and Reset\">"
    "<INPUT type=\"submit\" name=\"FORMATFS\" value=\"!!! Format fs !!!\">"
    "</div>"
    "</FORM>"
    "</body>"
    "</html>";
    httpServer.send(200, "text/html", html); 
}

void handleSubmit() {
  saveConfigValue("mac", httpServer.arg("MAC"));
  saveConfigValue("ssid", httpServer.arg("SSID"));
  saveConfigValue("password", httpServer.arg("PASSWORD"));
  saveConfigValue("adminpwd", httpServer.arg("ADMINPWD"));
  saveConfigValue("hostname", httpServer.arg("HOSTNAME"));
  saveConfigValue("rotorsteps", httpServer.arg("ROTORSTEPS"));
}

void handleReset() {
  httpServer.send(200, "text/plain", "restart ..."); 
  ESP.restart();
}

void handleFormat() {
  Serial.print("Format fs ... ");
  SPIFFS.format();
  setupFileSystem();
  Serial.println("ready");
}

void handleHttp404() {
  httpServer.send(404, "text/plain", "404: Not found"); 
}

void setupIo() {
  ESP.eraseConfig();
  WiFi.setAutoConnect(false);

  pinMode(ROT_AZI_STEP, OUTPUT);
  pinMode(ROT_AZI_DIR, OUTPUT);
  pinMode(ROT_AZI_ENABLED, OUTPUT);
  pinMode(ROT_AZI_LIMIT_SWITCH,INPUT_PULLUP);
  pinMode(SW1PIN, INPUT);
  pinMode(SW2PIN, INPUT);
  //pinMode(DISPLAY_SDA,OUTPUT);
  //pinMode(DISPLAY_SCL,OUTPUT);
  
}

void setupFileSystem() {
  if(!SPIFFS.begin()) {
    SPIFFS.format();
    SPIFFS.begin(); 
  }

  
  if(!SPIFFS.exists(getConfigFilename("mac"))) {
    String mac=WiFi.macAddress();
    mac.replace(":","-");
    saveConfigValue("mac", mac);
  }
  if(!SPIFFS.exists(getConfigFilename("ssid"))) saveConfigValue("ssid", "wlan-ssid");
  if(!SPIFFS.exists(getConfigFilename("password"))) saveConfigValue("password", "wlan-password");
  if(!SPIFFS.exists(getConfigFilename("adminpwd"))) saveConfigValue("adminpwd", "123456789ff");
  if(!SPIFFS.exists(getConfigFilename("hostname"))) saveConfigValue("hostname", "node");
  if(!SPIFFS.exists(getConfigFilename("pubtopic"))) saveConfigValue("pubtopic", "temp/sensor");
  if(!SPIFFS.exists(getConfigFilename("rotorsteps"))) saveConfigValue("rotorsteps", "0");

}

void setupWifiAP(){
  Serial.println("Setup shell is starting ...");
  String pwd=readConfigValue("adminpwd");

  if(pwd==""){
    Serial.println("Use default password!");
    pwd="0000";
  }
  
  Serial.print("Password for AP:");
  Serial.println(pwd);
  
  WiFi.mode(WIFI_AP);
  WiFi.softAP("rotor.dk9mbs.de", pwd);

  Serial.println("AP started");
  
  printLcd(lcd, 0,0, WiFi.softAPIP(),1);
  printLcd(lcd, 0,1, pwd,0);

}

boolean setupWifiSTA(const char* ssid, const char* password, const char* newMacStr) {
  int timeoutCounter=0;
  int timeout=20;
  
  uint8_t mac[6];
  byte newMac[6];
  parseBytes(newMacStr, '-', newMac, 6, 16);

  clearLcdLine(lcd,0);
  printLcd(lcd, 0,0, "Connecting WLAN",0);

  WiFi.setAutoReconnect(true);

  if(newMacStr != "") {
    wifi_set_macaddr(0, const_cast<uint8*>(newMac));
    Serial.println("mac address is set");
  }
  
  wifi_station_set_hostname(readConfigValue("hostname").c_str());
  Serial.print("Hostname ist set: ");
  Serial.println(readConfigValue("hostname"));
  
  delay(10);
  Serial.print("Connecting to ");
  Serial.println(ssid);
  WiFi.mode(WIFI_STA);
  Serial.print("Password:");
  Serial.println("***********");
  
  WiFi.begin(ssid, password);
  
  Serial.println("after WiFi.begin():");
  
  while (WiFi.status() != WL_CONNECTED) {
    delay(500);
    Serial.print(".");
    timeoutCounter++;
    clearLcdLine(lcd,1);
    printLcd(lcd, 0,1, String(timeoutCounter)+"/"+String(timeout),0);
    if (timeoutCounter>timeout) return false;
    
  }

  WiFi.macAddress(mac);
  
  Serial.println("WiFi connected");
  Serial.print("IP address:");
  Serial.println(WiFi.localIP());
  Serial.printf("Mac address:%02x:%02x:%02x:%02x:%02x:%02x\n",mac[0],mac[1],mac[2],mac[3],mac[4],mac[5]);
  Serial.printf("Mac address:%s\n", WiFi.macAddress().c_str());
  Serial.print("Subnet mask:");
  Serial.println(WiFi.subnetMask());
  Serial.print("Gateway:");
  Serial.println(WiFi.gatewayIP());

  printLcd(lcd, 0,0, WiFi.localIP(),1);
  printLcd(lcd, 0,1, "AG5ZL Rotor",0);

  return true;
}

/*
 * Display
 */
void clearLcdLine(LiquidCrystal_I2C& lcdDisplay,int line){
  for(int n = 0; n < 16; n++) {  // 20 indicates symbols in line. For 2x16 LCD write - 16
    lcdDisplay.setCursor(n,line);
    lcdDisplay.print(" ");
  }
  lcdDisplay.setCursor(0,line);             // set cursor in the beginning of deleted line
}
 
void printLcd(LiquidCrystal_I2C& lcdDisplay,int column, int row, IPAddress text, int clear) {
  if(clear==1) lcdDisplay.clear();
  
  lcdDisplay.setCursor(column, row); // Spalte, Zeile
  lcdDisplay.print(text);
} 
void printLcd(LiquidCrystal_I2C& lcdDisplay,int column, int row, String text, int clear) {
  if(clear==1) {
    lcdDisplay.clear();
  }
  
  lcdDisplay.setCursor(column, row); // Spalte, Zeile
  lcdDisplay.print(text);
}

//class StepperRequest {
//  public:
//    static int _newPos;
//    static int _currentPos;
//    static int _maxSteps;
//    static boolean _init;
//    
//    static int getNewPos();
//    static void setNewPos(int value);
//
//    static int getCurrentPos();
//    static void setCurrentPos(int value);
//    static void incrementCurrentPos();
//    static void decrementCurrentPos();
//
//    static void incrementMaxSteps();
//    static int getMaxSteps();
//
//    static void setInit(boolean init);
//    static boolean getInit();
//    
//};
//
//int StepperRequest::_newPos=0;
//
//int StepperRequest::getNewPos() {
//  return StepperRequest::_newPos;
//}
//void StepperRequest::setNewPos(int value) {
//  StepperRequest::_newPos=value;
//}
//
//int StepperRequest::_currentPos=0;
//int StepperRequest::getCurrentPos() {
//   return StepperRequest::_currentPos;
//}
//void StepperRequest::setCurrentPos(int value) {
//   StepperRequest::_currentPos=value;
//}
//void StepperRequest::incrementCurrentPos() {
//   StepperRequest::_currentPos++;
//}
//void StepperRequest::decrementCurrentPos() {
//   StepperRequest::_currentPos--;
//}
//
//
//int StepperRequest::_maxSteps=0;
//void StepperRequest::incrementMaxSteps() {
//  StepperRequest::_maxSteps++;
//}
//int StepperRequest::getMaxSteps() {
//  return StepperRequest::_maxSteps;
//}
//
//boolean StepperRequest::_init=false;
//void StepperRequest::setInit(boolean value) {
//  StepperRequest::_init=value;
//}
//boolean StepperRequest::getInit(){
//  return StepperRequest::_init;
//}

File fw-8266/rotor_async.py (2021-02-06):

import json
import sys
import network
import machine
import utime

try:
    import usocket as socket
except:
    import socket


f=open('config.json')
cfg=json.loads(f.read())

#
# WLAN functions
#
def do_connect(essid, password):
    sta_if = network.WLAN(network.STA_IF)
    ap_if = network.WLAN(network.AP_IF)
    ap_if.active(False)
    print("starting network ...")
    if not sta_if.isconnected():
        print('connecting to network...')
        sta_if.active(True)
        sta_if.connect(essid, password)
        while not sta_if.isconnected():
            print(".")
            pass
    print('network config:', sta_if.ifconfig())


#
# Shared Memory class for exchange objects and values between instances
#
class SharedMemory:
    _azi_stepper=None

    @classmethod
    def create_azi_stepper(cls):
        if cls._azi_stepper==None:
            print("Create new azi stepper instance")
            cls._azi_stepper=Stepper(step_size_deg=0.06, step_period_ms=4)
            cls._azi_stepper.init()

        return cls._azi_stepper

#
# Stepper 8255 class
#


class Stepper:
    def __init__(self,**kwargs):
        self._step_size_deg=float(kwargs['step_size_deg'])
        self._step_period_ms=int(kwargs['step_period_ms'])
        self._pin_step = machine.Pin(12, machine.Pin.OUT)
        self._pin_dir = machine.Pin(13, machine.Pin.OUT)
        self._pin_enabled = machine.Pin(14, machine.Pin.OUT)
        self._pin_limit_switch = machine.Pin(5, machine.Pin.IN, machine.Pin.PULL_UP)
        self._current_pos_deg=0

    def get_pin_enabled(self):
        return self._pin_enabled

    def get_pin_step(self):
        return self._pin_step

    def get_pin_dir(self):
        return self._pin_dir

    def get_pin_limit_switch(self):
        return self._pin_limit_switch

    def get_current_pos_deg(self):
        return self._current_pos_deg

    async def init(self, callback=None):
        #self._pin_enabled.value(0)
        await self.activate()

        # move the axis backwards
        self.init_dir(-1)
        moved_deg=0
        while not self.is_limit_switch_pressed():
            if not callback==None:
                callback(".")
            await self.do_step(1)
            moved_deg+=self._step_size_deg
            if moved_deg >=360:
                await self.deactivate()
                return False

        # move the axis forewards
        self.init_dir(1)
        while self.is_limit_switch_pressed():
            await self.do_step(1)

        for _ in range(0,100):
            await self.do_step(1)

        print("Limit switch: %s" % self._pin_limit_switch.value())
        #self._pin_enabled.value(1)
        await self.deactivate()
        self._current_pos_deg=0

        return True

    async def deactivate(self):
        self._pin_enabled.value(1)

    async def activate(self):
        self._pin_enabled.value(0)

    async def do_step(self, wait_ms):
        self._pin_step.value(1)
        await uasyncio.sleep_ms(wait_ms)
        #utime.sleep_ms(wait_ms)
        self._pin_step.value(0)
        await uasyncio.sleep_ms(wait_ms)
        #utime.sleep_ms(wait_ms)
    #
    # set the direction by the factor:
    # 1=forward (for example: 270 -> 360)
    # -1=back (for example: 360 -> 270)
    #
    def init_dir(self, factor):
        if factor==1:
            self._pin_dir.value(0)
        elif factor==-1:
            self._pin_dir.value(1)

    #
    # return True or False
    #
    def is_limit_switch_pressed(self):
        if self.get_pin_limit_switch().value()==1:
            return True
        else:
            return False

    #
    # Move the stepper to the target possition (deg)
    #
    async def move(self, pos_deg):
        if self._current_pos_deg<pos_deg:
            factor=1
            self.init_dir(factor)
            delta_deg=pos_deg-self._current_pos_deg
        else:
            factor=-1
            self.init_dir(factor)
            delta_deg=self._current_pos_deg-pos_deg

        # calculate the steps from degrees to steps
        delta_steps=int(delta_deg/self._step_size_deg)
        self._pin_enabled.value(0)

        print("Moving stepper: %s" % delta_steps)
        steps_moved=0
        for x in range(0, delta_steps):
            if self.is_limit_switch_pressed():
                print("limit switch detected")
                break

            await self.do_step(0)
            steps_moved+=1

        self._pin_enabled.value(1)

        print("Steps moved %s:" % steps_moved)
        self._current_pos_deg=self._current_pos_deg+(steps_moved*self._step_size_deg*factor)

#
# http server classes
#
class WebRequest:
    def __init__(self, f):
        self._header=[]
        self._method=""
        self._request_url=""
        #read the first line with method request url and http version
        req = str(f.readline().decode()).split(" ")
        self._request_url=req[1]
        #read the header until end of header
        while True:
            line = f.readline()
            self._header.append(line)
            if not line or line == b'\r\n':
                break

    def get_request_url(self):
        return self._request_url

class WebResponse:
    def __init__(self, client):
        self._client=client
        pass
    
    def print(self, text):
        self._client.send(text)
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

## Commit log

2021-01-03 Limit switch implemented
2021-01-10 Exception in case of missing limit switch
    [rotor.py]
2021-01-10 bugfix: always disable the 8825
    [rotor.py]
2021-02-13 initialize max stepper steps
2021-02-17 Changed True / High für Limit Switch
2021-02-22 3D files added
    [Normteile.FCStd, Rotor_Adapter_Zahnrad.FCStd, Rotor_Antrieb.FCStd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]
